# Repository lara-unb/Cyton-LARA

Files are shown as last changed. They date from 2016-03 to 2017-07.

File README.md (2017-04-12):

# Cyton-LARA
Cyton Alpha 7D1G is a 7 DOF Robot Arm developed by Robai. It presents 9 servo motors controlled by a SSC-32 board. However, the servo motors does not provide position feedback. For this reason, the Cyton Alpha only allows open-loop projects, restricting a lot the possibilities of development. This project has as main goal closing the loop of the Cyton arm and developing a Matlab-Arduino user interface with some functions.  

<div style="text-align:center">
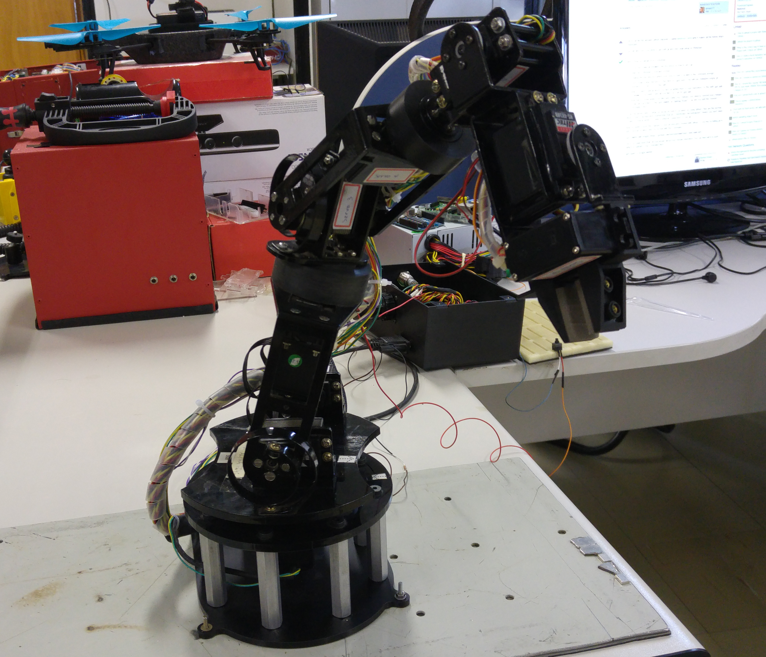
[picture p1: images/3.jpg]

</div>

## Hardware Required
1. Cyton Alpha 7D1G
2. Arduino Mega

## Software Required
1. Arduino IDE
2. Matlab

## Hardware Modification - Closing the Loop
In order to close the loop of the arm, it is necessary to get the position of each servo motor (only 7 of them). Each servo motor has a potentiometer inside. Somehow, most of them doesn't have a wire solded on it. The ideia is to open the servos and sold a wire on the potentiometer. Doing so, for each servo position, the potentiometer will show a different voltage. Also, it is possible to see that the voltage grows linearly according to the servo position. Obs.: Do this at your own risk.
<div style="text-align:center">
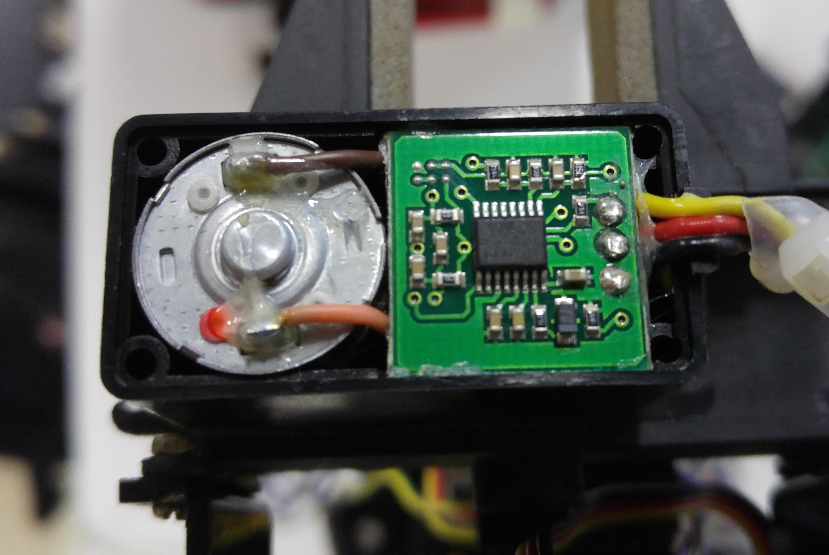
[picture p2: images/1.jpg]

</div>
<div style="text-align:center">
some text
</div>

## Arduino Mega
The Cyton C++ API provided by Robai is a good way to program the arm, however, as we are working with the feedback, the Arduino Mega is included in the hardware for reading the servo voltage values and also to execute the servo movement. How? Plugging a wire on the Arduino Mega TX1 port on the SSC-32 RX port will allow to communicate both boards through Serial1. This allow us to use the Serial to connect with ROS. Also, it is needed to plug a wire from Arduino Ground to the SSC-32 ground. It is recommended to set the baud rate of SSC-32 to 9600 (just disconnect to first jumper located in the BAUD section of the board). And one final detail: connect the Arduino AREF port tot he 3.3 V port in order to augment the servo feedback resolution.
<div style="text-align:center">
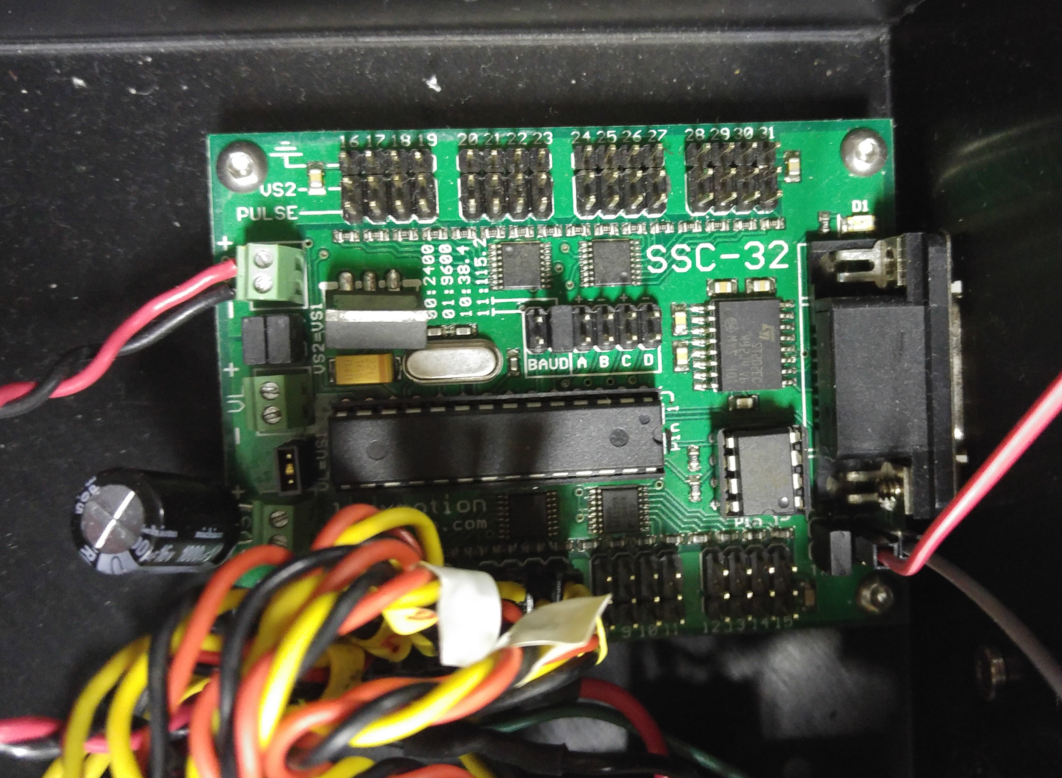
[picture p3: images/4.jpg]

</div>

## Matlab
The Matlab is mainly used to calculate the Forward Kinematics of the arm, as the Arduino is not powerful enough to do so. Also, it is used to present the User Interface with a Menu with some options.

## Required Arduino Libraries
1. LibSSC32: modified from [original](https://martinperis.blogspot.com.br/2011/05/libssc32-arduino-ssc32.html) to use port TX1 instead TX
2. Filters: https://github.com/JonHub/Filters
3. StandardCplusplus: https://github.com/maniacbug/StandardCplusplus

## Required Maltab Toolbox
1. DQ Robotics: http://dqrobotics.sourceforge.net/

## Required ROS Package
1. Rosserial: http://wiki.ros.org/rosserial

## DH Parameters
theta =  [0, 0, 0, 0, pi, pi/2, 0]  
d =     [0.0379, -0.0046, 0.145, -0.011, 0.175, 0.0074, 0.0]  
a =     [0.0, 0.0, 0.0, 0.0, 0.0, 0.0, 0.0677]  
alpha = [0, pi/2, -pi/2, pi/2, -pi/2, pi/2, pi/2]

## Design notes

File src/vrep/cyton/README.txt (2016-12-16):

Dentro da pasta "cyton" contém uma cena do vrep pronta para ser usada. 
Dentro de cyton_description, estão contidos os arquivos .stl e .urdf.
Caso queira abrir abrir o .urdf basta ir em cyton_description>robots e importar o "cyton_description",
no V-REP essa função de importar está na aba de "Plugins".

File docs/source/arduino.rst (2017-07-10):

Arduino Mega
============

Cyton was connected with an `Arduino Mega`_ to provided joint angle feedback and allow control trough USB with ROS.

.. _Arduino Mega :  https://www.arduino.cc/en/Main/arduinoBoardMega

Servo Control - Lynx SSC32
--------------------------

Joing Angles Feedback
---------------------

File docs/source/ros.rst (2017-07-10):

ROS
===

The Robot Operating System (`ROS`_) is a flexible framework for writing robot software. It is a collection of tools, libraries, and conventions that aim to simplify the task of creating complex and robust robot behavior across a wide variety of robotic platforms.

.. _ROS: http://www.ros.org/

Robot Description 
-----------------

Rosserial
---------

MoveIt!
-------

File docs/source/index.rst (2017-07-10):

.. Cyton-Lara documentation master file, created by
   sphinx-quickstart on Fri Dec 16 10:43:30 2016.
   You can adapt this file completely to your liking, but it should at least
   contain the root `toctree` directive.

Welcome to Cyton-Lara's documentation!
======================================

.. toctree::
   :maxdepth: 2
   :caption: Project

   history.rst
   authors.rst

   :Contents:

Indices and tables
==================

* :ref:`genindex`
* :ref:`modindex`
* :ref:`search`

* :ref:`hard-docs`
* :ref:`soft-docs`

.. _hard-docs:

.. toctree::
   :maxdepth: 2
   :caption: Hardware

   cyton.rst
   arduino.rst
   ssc32.rst

.. _soft-docs:

.. toctree::
   :maxdepth: 2
   :caption: Software

   ros.rst

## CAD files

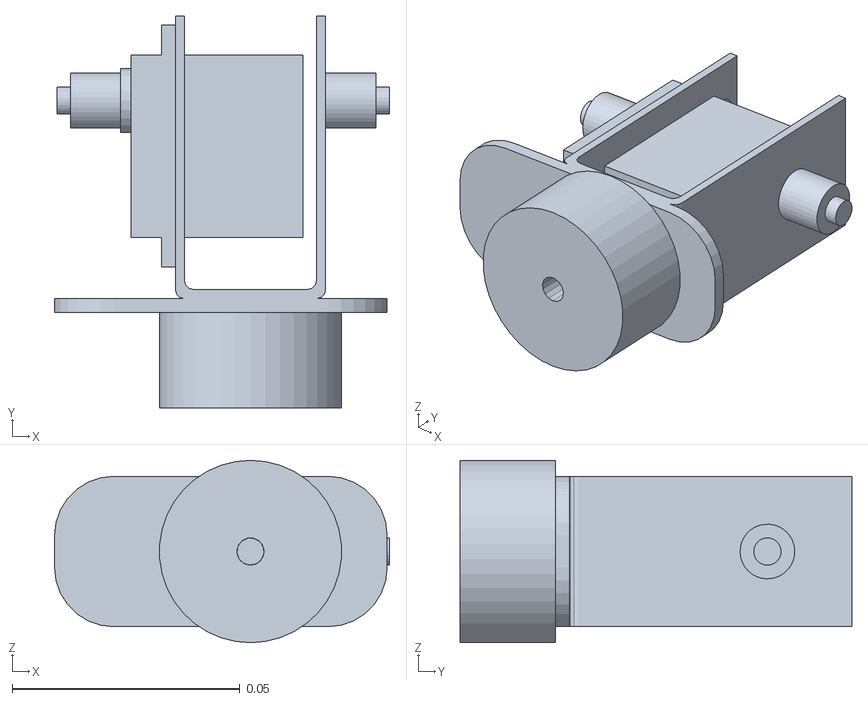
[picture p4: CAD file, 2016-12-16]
src/vrep/cyton/cyton_description/meshes/link3.STL
0.0735 x 0.086 x 0.04

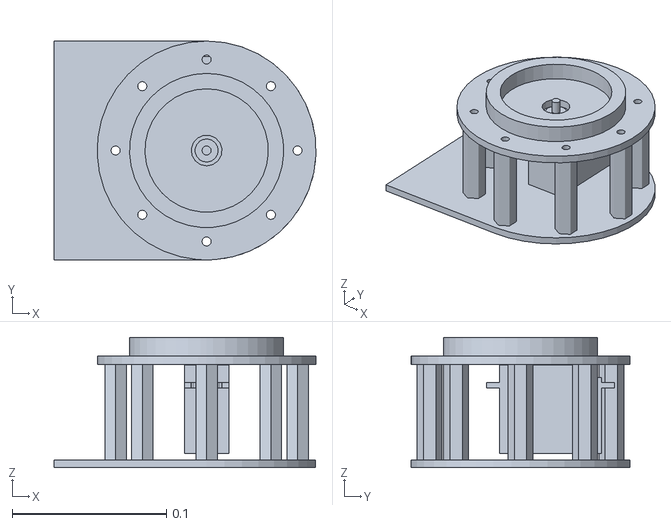
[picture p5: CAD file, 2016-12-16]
src/vrep/cyton/cyton_description/meshes/link0.STL
0.17 x 0.142 x 0.0845

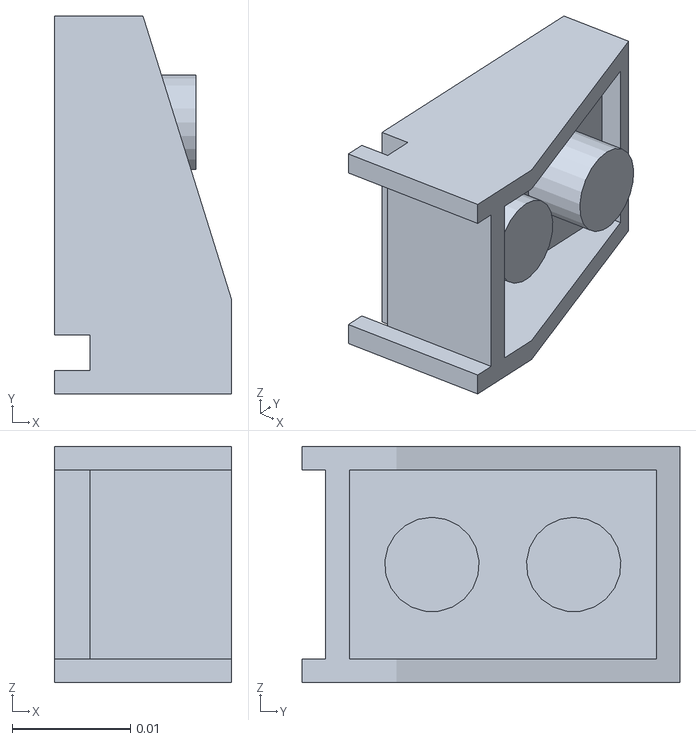
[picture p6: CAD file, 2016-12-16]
src/vrep/cyton/cyton_description/meshes/claw2.STL
0.015 x 0.032 x 0.02

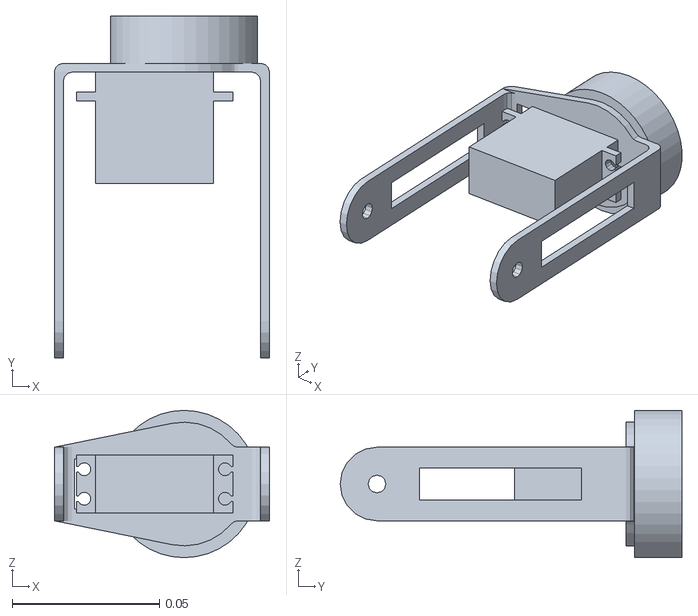
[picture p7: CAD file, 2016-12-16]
src/vrep/cyton/cyton_description/meshes/link4.STL
0.073 x 0.116 x 0.05

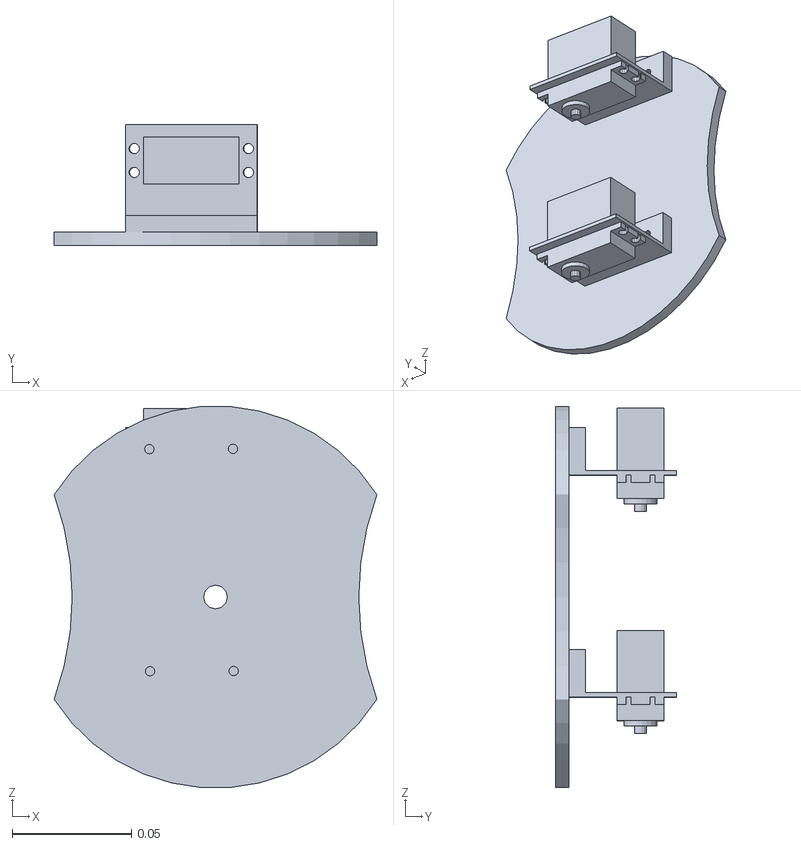
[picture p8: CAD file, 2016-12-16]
src/vrep/cyton/cyton_description/meshes/link1.STL
0.135 x 0.0505 x 0.16

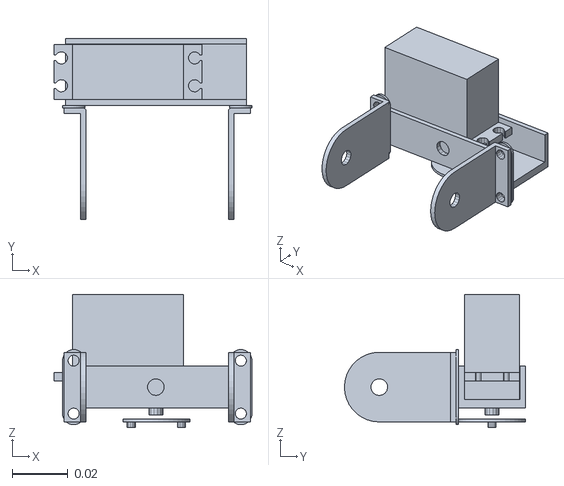
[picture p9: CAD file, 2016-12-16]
src/vrep/cyton/cyton_description/meshes/link7.STL
0.0711 x 0.065 x 0.0477

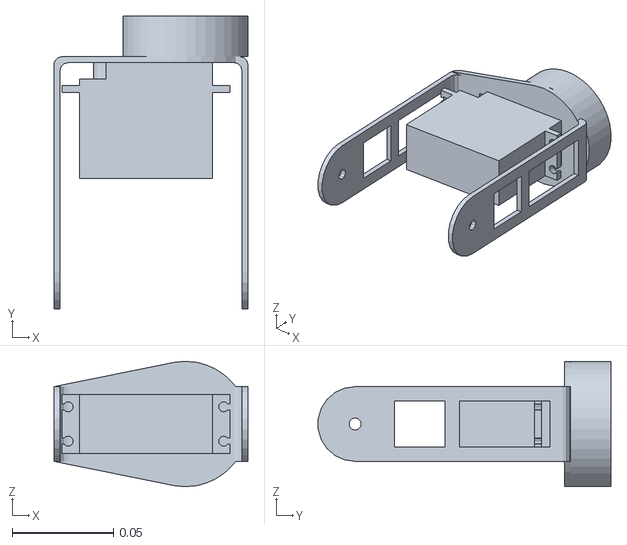
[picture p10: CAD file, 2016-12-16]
src/vrep/cyton/cyton_description/meshes/link2.STL
0.096 x 0.145 x 0.062

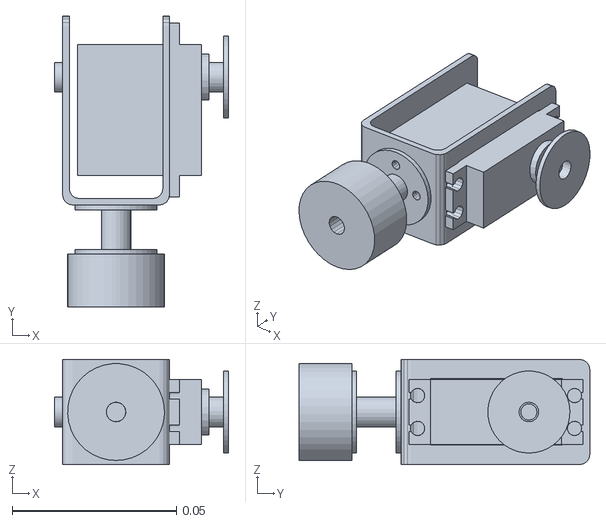
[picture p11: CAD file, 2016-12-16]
src/vrep/cyton/cyton_description/meshes/link5.STL
0.053 x 0.0885 x 0.032

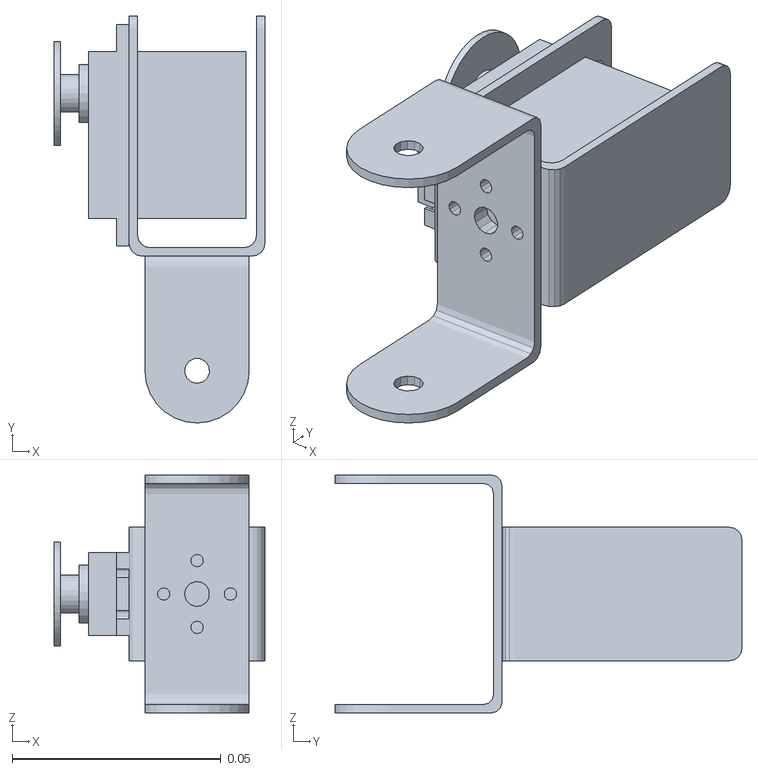
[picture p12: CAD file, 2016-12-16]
src/vrep/cyton/cyton_description/meshes/link6.STL
0.0505 x 0.0975 x 0.057

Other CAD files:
src/vrep/cyton/cyton_description/meshes/claw1.STL

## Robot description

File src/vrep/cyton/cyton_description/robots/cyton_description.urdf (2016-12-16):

<robot name="cyton_description">
  <link name="link0">
    <inertial>
      <origin xyz="0.093366 0.03803 0.065977" rpy="0 0 0" />
      <mass value="0.40583" />
      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
    </inertial>
    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
  </link>
  <link name="link1">
    <inertial>
      <origin xyz="-0.0045279 0.015309 0.0058769" rpy="0 0 0" />
      <mass value="0.17897" />
      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
    </inertial>
    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
  </link>
  <joint name="shoulder_base" type="revolute">
    <origin xyz="0.099 -0.071 0.0845" rpy="1.5708 -3.382E-20 -3.141" />
    <parent link="link0" />
    <child link="link1" />
    <axis xyz="0 -1 0" />
    <limit lower="-1.5708" upper="1.5708" effort="1000" velocity="6.2832" />
  </joint>
  <link name="link2">
    <inertial>
      <origin xyz="-0.0065594 0.081209 -2.1283E-10" rpy="0 0 0" />
      <mass value="0.17025" />
      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
    </inertial>
    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
  </link>
  <joint name="shoulder_pitch" type="revolute">
    <origin xyz="0 0.0355 0" rpy="3.1416 -1.568 3.1416" />
    <parent link="link1" />
    <child link="link2" />
    <axis xyz="1 0 0" />
    <limit lower="-1.4835" upper="1.4835" effort="1000" velocity="6.2832" />
  </joint>
  <link name="link3">
    <inertial>
      <origin xyz="-0.0037056 0.037257 4.318E-06" rpy="0 0 0" />
      <mass value="0.074076" />
      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
    </inertial>
    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
  </link>
  <joint name="shoulder_yaw" type="revolute">
    <origin xyz="0.008 0.1065 0" rpy="0 4.1059E-05 0" />
    <parent link="link2" />
    <child link="link3" />
    <axis xyz="0 -1 0" />
    <limit lower="-1.5708" upper="1.5708" effort="1000" velocity="6.2832" />
  </joint>
  <link name="link4">
    <inertial>
      <origin xyz="-0.00453034281205507 0.0720346348332056 -1.35437425163865E-09" rpy="0 0 0" />
      <mass value="0.0672668972309732" />
      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
    </inertial>
    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
  </link>
  <joint name="elbow_pitch" type="revolute">
    <origin xyz="0 0.06745 0" rpy="0 -4.996E-14 0" />
    <parent link="link3" />
    <child link="link4" />
    <axis xyz="1 0 0" />
    <limit lower="-1.4835" upper="1.4835" effort="1000" velocity="6.2832" />
  </joint>
  <link name="link5">
    <inertial>
      <origin xyz="0.00456829669603721 0.0474224526162388 -3.47375755178903E-06" rpy="0 0 0" />
      <mass value="0.051376442823963" />
      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
    </inertial>
    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
  </link>
  <joint name="wrist_roll" type="revolute">
    <origin xyz="0.0015 0.0875 0" rpy="3.1416 0.0004604 3.1416" />
    <parent link="link4" />
    <child link="link5" />
    <axis xyz="0 -1 0" />
    <limit lower="-1.5708" upper="1.5708" effort="1000" velocity="6.2832" />
  </joint>
  <link name="link6">
    <inertial>
      <origin xyz="-0.0052229 0.050156 0.0077539" rpy="0 0 0" />
      <mass value="0.045233" />
      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
    </inertial>
    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
  </link>
  <joint name="wrist_yaw" type="revolute">
    <origin xyz="0 0.06995 0" rpy="0 1.5708 0" />
    <parent link="link5" />
    <child link="link6" />
    <axis xyz="0 0 -1" />
    <limit lower="-1.1345" upper="1.1345" effort="1000" velocity="6.2832" />
  </joint>
  <link name="link7">
    <inertial>
      <origin xyz="-0.016212 0.037635 0.009234" rpy="0 0 0" />
      <mass value="0.04349" />
      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
    </inertial>
    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
  </link>
  <joint name="wrist_pitch" type="revolute">
    <origin xyz="0 0.06645 0.00775" rpy="0 -3.4333E-11 0" />
    <parent link="link6" />
    <child link="link7" />
    <axis xyz="-1 0 0" />
    <limit lower="-1.1781" upper="1.1781" effort="1000" velocity="6.2832" />
  </joint>
  <link name="claw1">
    <inertial>
      <origin xyz="0.0052069 0.010995 1.4043E-05" rpy="0 0 0" />
      <mass value="0.0052092" />
      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
    </inertial>
    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
  </link>
  <joint name="claw_right" type="prismatic">
    <origin xyz="-0.0091826 0.0555 0" rpy="0 0.0026969 0" />
    <parent link="link7" />
    <child link="claw1" />
    <axis xyz="1 0 0.0026969" />
    <limit lower="0" upper="0.017" effort="1000" velocity="0.017" />
  </joint>
  <link name="claw2">
    <inertial>
      <origin xyz="0.0053418 0.010995 -8.0075E-14" rpy="0 0 0" />
      <mass value="0.0052092" />
      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
    </inertial>
    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
  </link>
  <joint name="claw_left" type="prismatic">
    <origin xyz="-0.0091826 0.0555 0" rpy="3.1416 4.6484E-13 3.1416" />
    <parent link="link7" />
    <child link="claw2" />
    <axis xyz="-1 0 0" />
    <limit lower="-0.017" upper="0" effort="1000" velocity="0.017" />
  </joint>
</robot>

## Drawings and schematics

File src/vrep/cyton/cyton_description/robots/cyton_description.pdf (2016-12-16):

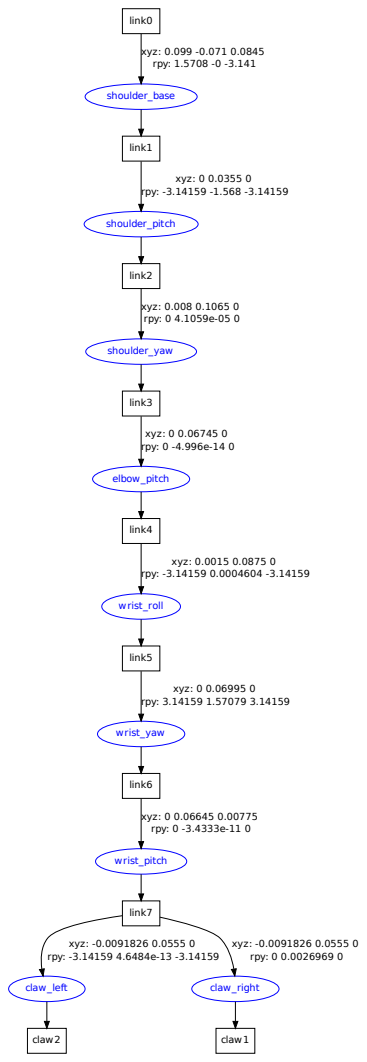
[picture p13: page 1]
link0; shoulder_base; xyz: 0.099 -0.071 0.0845 rpy: 1.5708 -0 -3.141; link1; shoulder_pitch; xyz: 0 0.0355 0 rpy: -3.14159 -1.568 -3.14159; link2; shoulder_yaw; xyz: 0.008 0.1065 0 rpy: 0 4.1059e-05 0; link3; elbow_pitch; xyz: 0 0.06745 0 rpy: 0 -4.996e-14 0; link4; wrist_roll; xyz: 0.0015 0.0875 0 rpy: -3.14159 0.0004604 -3.14159; link5; wrist_yaw; xyz: 0 0.06995 0 rpy: 3.14159 1.57079 3.14159; link6; wrist_pitch; xyz: 0 0.06645 0.00775 rpy: 0 -3.4333e-11 0; link7; claw_left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

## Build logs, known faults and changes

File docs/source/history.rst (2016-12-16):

=======
History
=======

Version Alpha
-------------
First version. Arm Controled using API for SSC-32. Communication trough serial port RS-323.

Version 1.0 - Feedback Included
-------------------------------

Hardware modified to allow direct feedback from robot joints position. Robot controled by USB using a Arduino Mega as interface to SSC-32 board and joint potentiometers.

Version 1.1 - Basic ROS Integration
-----------------------------------

Robot comunication with ROS trough serial port by the Arduino Mega. Hardware modified allowing use of multiple Serial communication ports.

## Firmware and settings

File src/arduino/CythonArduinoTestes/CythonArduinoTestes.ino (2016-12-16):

/** 
 * Universidade de Brasília
 * Laboratório de Automação e Robótica
 * @authors De Hong Jung , Rafael Lima
 * Programa: Recebe diversos comandos eviados do Matlab e as executa enviando 
 *           comandos via serial para o manipulador Cyton Alpha 7D1G
 */
 
#include <SSC32.h>

#include <StandardCplusplus.h>
#include <system_configuration.h>
#include <unwind-cxx.h>
#include <utility.h>
#include <serstream>
#include <sstream>
#include <string>
#include <vector>
#include <iterator>

using namespace std;

//=========================== Variaveis =================================

float value = 0.0;
float erro = 0.0, servoPosicaoMap = 0.0;
int count, k, duration;
vector <float> angles_ref;
vector <float> angles_feedback;
vector <float> ang0;vector <float> ang1;vector <float> ang2;vector <float> ang3;vector <float> ang4;vector <float> ang5;vector <float> ang6;
vector <float> ang;

// Minimo e Maximo em Volts
float min_array[] = {2.72, 0.7, 2.7, 4.06, 2.7, 2.7, 2.75, 2.69};
float max_array[] = {0.75, 4.26, 0.75, 0.45, 0.63, 0.63, 0.6, 0.69};

// Minimo e Maximo do Servo
float min_array2[] = {2330, 2320, 2350, 800, 2370, 2300, 2370};
float max_array2[] = {720, 920, 730, 2100, 610, 600, 580};
float min_degree[] = {-90,-86, -90, -83, -90, -90,-90};
float max_degree[] = {90, 65, 90, 62, 90, 90, 90};

// Inputs
int servoPin = 6, servoPosicao, Input;

float Setpoint, Output;

//============= Classes ============================================

class PID{
public:
  
  float error;
  float sample;
  float lastSample;
  float kP, kI, kD;      
  float P, I, D;
  float pid;
  
  float setPoint;
  float lastProcess;
  
  PID(float _kP, float _kI, float _kD){
    kP = _kP;
    kI = _kI;
    kD = _kD;
  }
  
  void addNewSample(float _sample){
    sample = _sample;
  }
  
  void setSetPoint(float _setPoint){
    setPoint = _setPoint;
  }
  
  float process(){
    // Implementação P ID
    error = setPoint - sample;
    float deltaTime = (millis() - lastProcess) / 1000.0;
    lastProcess = millis();
    
    //P
    P = error * kP;
    
    //I
    I = I + (error * kI) * deltaTime;
    
    //D
    D = (lastSample - sample) * kD / deltaTime;
    lastSample = sample;
    
    // Soma tudo
    pid = P + I + D;
    
    return pid;
  }
};

PID servoPID0(-0.1, 0.005, 0.0005);PID servoPID1(-0.1, 0.005, 0.0005);PID servoPID2(-0.1, 0.005, 0.0005);
PID servoPID3(-0.1, 0.005, 0.0005);PID servoPID4(-0.1, 0.005, 0.0005);PID servoPID5(-0.1, 0.005, 0.0005);
PID servoPID6(-0.1, 0.005, 0.0005);

namespace std {
  ohserialstream cout(Serial);
}


SSC32 myssc = SSC32();

//=============== Funções =========================================

// Funcao de Mapaeamento de variavel float
float mapfloat(float x, float in_min, float in_max, float out_min, float out_max){
  
  return (float)(x - in_min) * (out_max - out_min) / (float)(in_max - in_min) + out_min;
 
}

// Leitura de String da Serial
String readSerial() {
  String inData = "";
  if (Serial.available() > 0) {
    int h = Serial.available();
    for (int i = 0; i < h; i++) {
      inData += (char)Serial.read();
    }
    return inData;
  }
  else {
    return "No connection";
  }
}

// Leitura de posicao dos servos
vector <float> Feedback(){
  vector <float> angles;
  
  for (int i = 0; i < 7; i++){
    value = analogRead(i)*(5.0/1023.0);
    value = mapfloat(value, min_array[i], max_array[i], -90, 90);
    angles.push_back(value);
  }
  return angles;
}

// Funcao de move todos os servos a partir de um vetor de angulos (em graus)
void setMultServos(vector <float> angles, int dt){
  
  myssc.beginGroupCommand(SSC32_CMDGRP_TYPE_SERVO_MOVEMENT);
  
  value = mapfloat(angles[0], min_degree[0], max_degree[0], min_array2[0], max_array2[0]);
  myssc.servoMoveTime(0, value, dt);
  value = mapfloat(angles[1], min_degree[1], max_degree[1], min_array2[1], max_array2[1]);
  myssc.servoMoveTime(1, value, dt);
  value = mapfloat(angles[2], min_degree[2], max_degree[2], min_array2[2], max_array2[2]);
  myssc.servoMoveTime(2, value, dt);
  value = mapfloat(angles[3], min_degree[3], max_degree[3], min_array2[3], max_array2[3]);
  myssc.servoMoveTime(3, value, dt);
  value = mapfloat(angles[4], min_degree[4], max_degree[4], min_array2[4], max_array2[4]);
  myssc.servoMoveTime(4, value, dt);
  value = mapfloat(angles[5], min_degree[5], max_degree[5], min_array2[5], max_array2[5]);
  myssc.servoMoveTime(5, value, dt);
  value = mapfloat(angles[6], min_degree[6], max_degree[6], min_array2[6], max_array2[6]);
  myssc.servoMoveTime(6, value, dt);
  
  myssc.endGroupCommand();

  delay(100);
}

// Controle PID
void PIDControl(vector <float> angles_float, vector <float> feedback){ 
  vector <float> pidOut;  
  
  // Setpoint
  servoPID0.setSetPoint(angles_float[0]);servoPID1.setSetPoint(angles_float[1]);servoPID2.setSetPoint(angles_float[2]);
  servoPID3.setSetPoint(angles_float[3]);servoPID4.setSetPoint(angles_float[4]);servoPID5.setSetPoint(angles_float[5]);
  servoPID6.setSetPoint(angles_float[6]);

  // Sample
  servoPID0.addNewSample(feedback[0]);servoPID1.addNewSample(feedback[1]);servoPID2.addNewSample(feedback[2]);
  servoPID3.addNewSample(feedback[3]);servoPID4.addNewSample(feedback[4]);servoPID5.addNewSample(feedback[5]);
  servoPID6.addNewSample(feedback[6]);

  // Process
  pidOut.push_back(servoPID0.process());pidOut.push_back(servoPID1.process());pidOut.push_back(servoPID2.process());
  pidOut.push_back(servoPID3.process());pidOut.push_back(servoPID4.process());pidOut.push_back(servoPID5.process());
  pidOut.push_back(servoPID6.process());

  // Compensation
  duration = 700;
  setMultServos(pidOut, duration);
    
}

// Função que lê a string de angulos da serial e a tranforma em vetor de angulos float
vector <float> ReadAngles(){
  
  vector <float> angles_float;

  angles_float.clear();
  if (Serial.available()){
    for (int i = 0; i < 7; i++)
      angles_float.push_back(Serial.readStringUntil(' ').toFloat());  
  }
  return angles_float;
}

// Executa a Forward Kinematics a partir dos angulos das juntas enviadas do Matlab
vector <float> FKM(){
  
  vector <float> angles_float;

  angles_float = ReadAngles();
  if (angles_float[0] == 999)
    return angles_float;
  else{
    duration = 700;
    setMultServos(angles_float, duration);
    return angles_float;
  }
}

// Funcao que inicializa todos os servos para posição 0 graus
void SetInitialPosition(){
  
  duration = 2000;

  myssc.beginGroupCommand(SSC32_CMDGRP_TYPE_SERVO_MOVEMENT);
  value = mapfloat(0, min_degree[0], max_degree[0], min_array2[0], max_array2[0]);
  myssc.servoMoveTime(0, value, duration);
  value = mapfloat(0, min_degree[1], max_degree[1], min_array2[1], max_array2[1]);
  myssc.servoMoveTime(1, value, duration);
  value = mapfloat(0, min_degree[2], max_degree[2], min_array2[2], max_array2[2]);
  myssc.servoMoveTime(2, value, duration);
  value = mapfloat(0, min_degree[3], max_degree[3], min_array2[3], max_array2[3]);
  myssc.servoMoveTime(3, value, duration);
  value = mapfloat(0, min_degree[4], max_degree[4], min_array2[4], max_array2[4]);
  myssc.servoMoveTime(4, value, duration);
  value = mapfloat(0, min_degree[5], max_degree[5], min_array2[5], max_array2[5]);
  myssc.servoMoveTime(5, value, duration);
  value = mapfloat(0, min_degree[6], max_degree[6], min_array2[6], max_array2[6]);
  myssc.servoMoveTime(6, value, duration);
//  value = mapfloat(0, min_array[7], max_array[7], -90, 90);
//  myssc.servoMoveTime(7,value,3000);
  myssc.endGroupCommand();
  
  delay(2000);

}

void Replay(){
    vector <float> angles;
    angles.push_back(0.0);
    
    for (int i = 0; i < ang0.size(); i++){
      angles.clear();
      angles.push_back(ang0[i]);angles.push_back(ang1[i]);angles.push_back(ang2[i]);
      angles.push_back(ang3[i]);angles.push_back(ang4[i]);angles.push_back(ang5[i]);
      angles.push_back(ang6[i]);

      duration = 500;
      setMultServos(angles, duration);
      delay(400);
    }
}

void Record(){
    int dt = 400;
    ang0.clear();ang1.clear();ang2.clear();
    ang3.clear();ang4.clear();ang5.clear();
    ang6.clear();
    
    while (!Serial.available()){
        angles_ref.clear();
        angles_ref = Feedback();
        ang0.push_back(angles_ref[0]);ang1.push_back(angles_ref[1]);ang2.push_back(angles_ref[2]);
        ang3.push_back(angles_ref[3]);ang4.push_back(angles_ref[4]);ang5.push_back(angles_ref[5]);
        ang6.push_back(angles_ref[6]);
        Serial.print(angles_ref[0]); Serial.print(' ');Serial.print(angles_ref[1]); Serial.print(' ');Serial.print(angles_ref[2]); Serial.print(' ');Serial.print(angles_ref[3]); Serial.print(' ');
        Serial.print(angles_ref[4]); Serial.print(' ');Serial.print(angles_ref[5]); Serial.print(' ');Serial.println(angles_ref[6]);
        delay(dt);
    }
    Input = Serial.parseInt();

    delay(1000);
}

//============== Setup ===========================================

void setup() {
  // Start Comunication with Servo Motors
  myssc.begin(9600);
  Serial.begin(9600);
  
  analogReference(EXTERNAL);  // Ligar porta AREF em 3.3V -> Aumenta resolução

  // Set all Angles to zero
  ang0.push_back(999);ang1.push_back(0.0);ang2.push_back(0.0);
  ang3.push_back(0.0);ang4.push_back(0.0);ang5.push_back(0.0);
  ang6.push_back(0.0);

  // Move Robot to Zero Position
  SetInitialPosition();
}

//=============== Loop ============================================

void loop() {
  // Feedback
  angles_feedback = Feedback();

  // Print Joint Angles
  for (k = 0; k < 7; k++){
     if (k == 6){
        Serial.println(angles_feedback[k]);
     }else{
        Serial.print(angles_feedback[k]);
        Serial.print(' ');
     }
  }

  // Move Robot to Zero Position
  SetInitialPosition();

  delay(10);
}

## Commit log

2016-04-28 Tirei os txt
2016-08-31 Started my own branch with DQrobotics Library
    [claw1.STL, claw2.STL, cyton_description.urdf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]
2016-09-05 Serial na Biblioteca LibSSC32 Modificada para Serial1
2016-09-09 Published Working on Arduino with rosserial_server
2016-09-16 Plotting joint angles script on matlab
2016-10-17 adicionado Biblioteca para gestão de tempo
2016-10-24 ROS Publisher/Subscriber working on Arduino and Python
